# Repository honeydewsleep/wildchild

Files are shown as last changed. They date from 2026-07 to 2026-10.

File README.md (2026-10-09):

# Energy Ring Remix — WLED Notification Light

A fully parametric OpenSCAD rebuild of the
[ENERGY RING (ESP32 + WLED)](https://makerworld.com/en/models/2045449-energy-ring-esp32-wled)
desk lamp by DSL Design, with three revisions for use as a fleet of
email/notification lights:

1. **The base screws together** (coarse single-start thread, ~1.4 turns)
   — no more leaving the bottom on the desk. The single-start thread
   stops at a deterministic rotation, so the USB opening lands aligned
   with the ESP32's USB port every time.
2. **Battery base options**: 4×AA as a "cube" (two 2×AA boxes stacked),
   4×AA flat (four in a row), and an 8×AA double-layer for 12 V strips.
   Batteries load through a screwed door on the underside, so nothing
   unscrews (and no wires twist) for a battery change.
3. **Double-sided ring**: the LED strip mounts around the inside of the
   outer rim firing inward, and translucent diffusers on BOTH the front
   and back faces glow with the light color.

There are **two part series**:

- **Series M ("matched")** — `scad/matched/`, dimensioned from the
  original model's STLs. Same outside dimensions and look as the
  original (Ø96 skirt, tapered Ø95→86.6 shell, Ø180×40 ring, identical
  Ø27.8 stem + snap-diffuser interfaces), but the shell **threads onto
  the chassis** instead of resting on it. Cross-compatible: the new
  double-sided ring fits an original base, and the original ring fits
  the new threaded base. **Print this series to extend your fleet.**
- **Series A ("generic")** — a self-consistent standalone design
  (Ø150 two-half ring in a slotted Ø92 base) built before the original
  files were available. Kept as an alternative aesthetic.

## The original's problem, measured

Slicing the original STLs shows the base is a tapered shell that simply
*rests* on the chassis cup (Ø82.5 barrel in a Ø82.9 mouth, held by
gravity) — that's the part that stays behind on the desk. Series M
replaces that slip joint with the clocked thread.

## What to print — Series M (matched, recommended)

| Configuration | Parts |
|---|---|
| USB powered | `shell_threaded.stl` (or `shell.stl`), `chassis.stl`, `ring_double_sided.stl`, 2× `ring_ds_diffuser.stl` |
| 4×AA battery (cube boxes) | shell + `chassis_bat_cube.stl`, `battery_door_cube.stl`, + ring parts |
| 4×AA battery (flat holder) | shell + `chassis_bat_flat4.stl`, `battery_door_flat.stl`, + ring parts |
| 8×AA / 12 V | shell + `chassis_bat_flat8.stl`, `battery_door_flat.stl`, + ring parts |
| Thread calibration | `thread_test_collar.stl` + any chassis (same thread as Series A) |

**Three shell options** (the ring's stem is threaded in all cases,
crest at the original Ø27.8):

- `shell_free.stl` + `stem_locknut.stl` — **position-anywhere**: the
  stem drops through a free-spinning bore; aim the ring at any angle,
  then screw the knurled locknut onto the stem from inside the base
  (reach in through the open bottom before the chassis goes on) and
  tighten. The shell top gets clamped between the ring's shoulder and
  the nut. Slip the nut over the wire bundle before connecting the
  wires.
- `shell_threaded.stl` — the ring **screws into the base** (~3.5
  turns) and stops facing forward (single-start; trim with
  `ring_clock_adjust` if your printer shifts the stop a few degrees).
- `shell.stl` — plain crush-rib collar: any ring *push-fits*, including
  unmodified original rings. The threaded ring's crests still grip in
  it, so rings are interchangeable across all shells and original
  bases.

**Bottom-port options** (`shell_free_port_button.stl` — port window at
the original notch position + front dismiss-button hole):

- **Cable through the window**: pair with any standard chassis; the
  USB-C plug passes through the 13×10 window (17×14 funneled mouth)
  and plugs into the board inside.
- **Panel jack in the base** (`chassis_jack.stl`): a Ø9.7 hole in a
  recessed panel across the barrel passage takes a 9.1 mm USB-C chassis
  jack (nut from the open interior, pigtail to the board's 5V/GND).
  The clocked thread lands the shell's window framing the jack. The
  port face sits ~8 mm behind the shell surface, so the plug's
  overmold must be slimmer than ~13×10 mm for its first centimeter —
  typical cable ends fit, extra-chunky ones may not. Flash the board
  before assembly (or use WLED OTA); the board's own USB port isn't
  reachable through the wall in this build.

Ring: print `ring_double_sided.stl` in your body color (the rims are
opaque; white bounces the most light) and the two `ring_ds_diffuser.stl`
trays in translucent/natural. The trays snap in with double beads
exactly like the original diffuser, at any rotation — the stem bulb
is surface-mounted outside the rim wall (like the original), so the
light cavity is completely clear. Print one tray opaque for a
single-sided ring. The COB strip runs the full inside of the rim,
ending at the Ø20 wire hole.

## What to print — Series A (generic)

| Configuration | Parts |
|---|---|
| USB powered (aligned split notch) | `base.stl`, `bottom_plate.stl`, 2× `ring_half.stl`, 2× `ring_diffuser.stl` |
| USB powered (zero-alignment option) | `base_wallhole.stl`, `bottom_plate_plain.stl`, + ring parts |
| 4×AA battery (cube boxes) | `base.stl`, `battery_tub_4aa_cube.stl`, `battery_door_cube.stl`, + ring parts |
| 4×AA battery (flat holder) | `base.stl`, `battery_tub_4aa_flat.stl`, `battery_door_flat.stl`, + ring parts |
| 8×AA / 12 V | `base.stl`, `battery_tub_8aa_flat.stl`, `battery_door_flat.stl`, + ring parts |
| Thread calibration | `thread_test_collar.stl` (bottom 12 mm of the base only) |

Print the two `ring_half.stl` copies in your opaque color (white interior
diffuses best) and the two `ring_diffuser.stl` copies in translucent/natural
filament. For a **single-sided** ring, print one diffuser translucent and
one in opaque white — same parts.

All STLs are exported print-ready (no supports needed):

- `base*.stl` prints inverted (as exported) — threads and notch face up.
- Plates/tubs print desk-face down — threads face up.
- Ring halves print face down; diffusers and doors print flat.
- The battery tub ceiling bridges over the pocket (internal, cosmetic only).

**Suggested settings:** 0.2 mm layers, 3 walls, 15 % infill. PETG or PLA.

## How the USB alignment works (both series)

The thread is single-start, so the fully-tightened joint always stops at
the same rotation. In Series M the USB hole lives in the shell wall and
the ESP32's port lives in the chassis; the clocked thread stops the hole
right in front of the port (the barrel passage is 5 mm wider than the
hole for slack). In CAD the alignment is exact at seat; first-layer
squish on a real printer can rotate the seat point slightly, so:

1. Print `thread_test_collar.stl` (cheap, fast) and a chassis (or plate).
2. Screw together until snug. If the notch lands rotated, estimate the
   offset in degrees (±10° already works).
3. Set `plate_clock_adjust` in `scad/params.scad` to that offset (flip
   the sign if it gets worse), re-render, reprint the male part only.

The value is per printer+profile — calibrate once and every chassis,
plate and battery tub you print after that will clock correctly. In
Series A you can skip the game entirely with `base_wallhole.stl` +
`bottom_plate_plain.stl` (window fully in the wall, nothing to align).

Threads are 45° flanks, 5 mm pitch, 0.3 mm radial clearance
(`thr_clr`) — loosen to 0.4 if your printer runs tight.

## Electronics

- ESP32 DevKit (30-pin) snaps between the rails on the chassis floor
  (Series M) or plate/tub (Series A), USB end toward the notch angle.
  Feed the USB cable through the hole *before* plugging it in; leave a
  service loop.
- COB WS2812B strip (10 mm wide): Series M ring takes ~550 mm around
  the Ø176 inside of the outer rim (~180 LEDs at 332/m — set a WLED
  current limit, e.g. 1800 mA on a 2 A supply); Series A ring takes
  ~455 mm. Stick it centered, LEDs facing the ring center; start/end
  the strip at the wire hole at the bottom of the rim.
- Series M: wires run down the Ø20 stem bore into the base; Series A:
  through the tab channel and slot-floor hole. Either way leave ~15 cm
  of slack so the base can be unscrewed with everything connected.

### Battery wiring

| Pack | Chemistry | Connect |
|---|---|---|
| 4×AA | **NiMH (recommended)** — 4.8 V nominal | Pack + → strip 5 V and ESP32 5 V pin, pack − → GND |
| 4×AA | Alkaline — 6.0 V fresh | Add 1–2 series diodes (1N5817) to stay ≤5.3 V for the strip |
| 8×AA | 12 V pack | 12 V strip (WS2815 or 12 V COB) direct; buck converter (MP1584 etc.) → 5 V for the ESP32 |

Pack leads route up through the 8 mm hole in the tub top plate. A KCD1
rocker switch snaps into the cutout on the front wall of every tub
(disable with `switch_cutout = false`). Battery door takes two M3×8
self-tapping screws.

*About "the battery boxes from the fume extractor project":* I couldn't
find that project in the repos this session can see, so the pockets are
sized for the common 58×31.5×15.5 mm 2×AA boxes and 62×58×15.5 mm flat
4×AA holders, with wiggle room. If yours differ, edit `pocket_cube` /
`pocket_flat4` / `pocket_flat8` in `scad/params.scad` (L×W×H + a couple
mm) and re-render.

## Ring assembly — Series M (matched)

1. Stick the COB strip around the inside of the outer rim, centered;
   start/end at the wire hole at the stem angle, wires down the stem.
2. Snap a diffuser tray into each face (double snap beads, exactly like
   the original diffuser — firm push all around). The trays also
   rigidify the ring, so snap both in before handling roughly.
3. Mount per your shell: `shell_free` — drop the stem in, aim the
   ring, slip the locknut up the wires and tighten it from inside;
   `shell_threaded` — screw the stem in clockwise (viewed from above)
   until the shoulder seats facing forward; `shell` — push the stem in
   until the crush ribs seat. Wires continue into the chassis in all
   cases.

## Ring assembly — Series A (generic)

1. Drop a diffuser into each half's rebate (it's captive after joining).
2. Stick the COB strip around the inside of one half's outer rim,
   centered on the joint line; route the wires through the tab groove.
3. Join the halves: the two alignment pins on each half enter the
   sockets on the other (flip one half over — the tab stays at the
   bottom by design). A few dabs of CA or plastic glue on the rim.
4. Seat the tab in the base slot, wires through the slot-floor hole.

## Email notifications (the whole point!)

WLED lamps take simple HTTP commands on your LAN, so a small bridge
watches Gmail and flips presets:

- **`companion/gmail_wled_bridge.py`** — standalone bridge, stdlib
  Python, runs on any always-on machine (Pi, desktop). Polls Gmail
  over IMAP for unread mail from specific senders (or Gmail labels),
  switches all lamps to that rule's WLED preset, and returns them to
  idle once the mail is read. Setup instructions in the file header.
- **Home Assistant alternative**: the `imap` integration fires an
  event per incoming mail; an automation matching the sender calls
  the WLED integration (`light.turn_on` with a color, or select the
  preset entity). Same idea, no extra script, if you already run HA.

Either way, save your looks as WLED presets (1 = idle, 2 = red
breathe, ...) so you can restyle in the WLED app without touching the
bridge. With WLED Sync (one lamp sends, the rest receive) a single
command drives every lamp in the house.

## Rendering

```bash
./render.sh          # everything: STLs, fit checks, preview PNGs
./render.sh stl      # just the printable STLs
./render.sh check    # thread interference/engagement verification
```

Requires OpenSCAD (tested with 2021.01).

## Roadmap

- **Other shapes (heart, peace sign, …)** — planned next, as discussed.
  The double-sided construction (two flip-symmetric halves + captive
  diffusers + tab) is shape-agnostic; the circle modules in
  `scad/ring.scad` will be generalized to arbitrary outlines. Note the
  peace sign's interior bars will need a lighting decision (lit bars vs
  silhouette bars).
- Printed-contact AA holder (springs from salvaged holders) if the
  purchased-box pockets don't suit.

## Misc: capsule-filling funnel (`scad/misc/capsule_funnel.scad`)

Mini funnel for hand-filling size 00 capsules with a powder that
doesn't want to flow. Standalone file, unrelated to the lamp.

- `capsule_funnel_00.stl` — the spout is a thin **socket that slips
  over the capsule body** (Ø8.48 ID, 5 mm deep), so the hole is only
  limited by the capsule's own bore: **Ø7.64 mm** for a 00. A tube
  that inserts *into* the body (`spout="in"`) can't beat ~Ø6.5.
  Steep 68° cone, Ø30 mouth, 0.8 mm cone wall, 0.6 mm socket wall,
  34 mm tall. Prints mouth-down, no supports.
- `capsule_funnel_00_insert.stl` — spout goes **into** the body
  instead (4 mm, Ø7.49 OD at the shoulder tapering to Ø7.29 at the
  tip), so nothing can spill between funnel and capsule. The tube wall
  is a **single 0.45 mm extrusion line**; turn on thin-wall detection /
  Arachne in the slicer. Hole **Ø6.39 mm**. The cone shoulder rests on
  the capsule rim as a depth stop. Too loose/tight → `insert_clr`
  (0.15 test-printed too big to enter; single-line walls swell).
- `capsule_tamper_00.stl` — Ø5.9 rod with a disc handle to break
  bridges and pack the powder down. Fits through either funnel.
- `capsule_stand_00.stl` — 52×52×14.5 block: 8 wells for bodies
  (front two rows, 12 mm deep so 8 mm stands proud) and 8 shallower
  wells for the caps (back two rows). Every well has a 45° lead-in.
  `stand_cols` / `stand_rows` / `stand_cap_row` change the count.
- `3mf/capsule_filler_kit.3mf` — all four parts named and laid out on
  the plate, centred on (90, 90) so it fits any Bambu bed (A1 mini
  included). Open it in Bambu Studio and slice with your own presets.
  Rebuilt by `render.sh` via `scripts/make_3mf.py`.
- Other sizes: `-D 'capsule="000"'` / `"0"` / `"1"` (body OD table in
  the file). Loosen `socket_clr` if the socket is tight on your prints.

## Misc: Katie Bakes cookie cutter (`scad/misc/katiebakes_cutter.scad`)

Cutter + embosser in one part for the "Katie Bakes" script wordmark:
the blade follows the lettering outline (5 mm dough border), a 2.5 mm
plate spans the top, and the letters hang 2 mm below it so they press
into the dough as you cut. Tuned for 6 mm rolled dough → 1.5 mm imprint
(`dough_t`, `imprint`). Lettering 100 mm wide (strokes ≥ 1.2 mm after a
0.15 mm `bold` offset); the cutter is ≈ 123 × 45 × 9 mm.

- `katiebakes_cutter.stl` — print as exported (plate on the bed, blade
  and letters up), no supports; PLA/PETG, 0.4 nozzle, 2+ perimeters.
- `katiebakes_stamp.stl` — stamp-only version: the same lettering 2 mm
  proud of a 3 mm plate (cookie outline inset 1 mm) with an 80 mm bar
  handle, ≈ 110 × 32 × 25 mm. The plate is the depth stop, so it works on
  any dough thickness. Print as exported: letter faces on the bed, handle
  up, no supports; enable elephant-foot compensation (~0.2 mm).
- `scad/misc/katiebakes_logo.svg` — cream face layer of the logo,
  colour-masked from `katie-bakes.jpg` and traced with potrace. Swap in
  another SVG (black fill, letters only) to re-use the cutter for a
  different logo; `logo_w` sets the size.

## Misc: 3" round Katie Bakes set (`scad/misc/katiebakes_round.scad`)

Etsy-style cutter + stamp set for the two-line logo ("Katie" over
"Bakes", `katiebakes_logo2.svg`, enclosing circle Ø66). Separate cutting
rings so different heights can be printed for different cookies; the
stamp prints face up for crisp, tall lettering and takes a screw-in
handle. All parts print as exported, no supports.

- `katiebakes_round_stamp.stl` — Ø75.2 × 8.5 mm disc, lettering 3 mm
  proud, female thread (root r7.0, depth 1.2, pitch 3, 6.5 deep,
  clearance 0.30) opening in the base. Print face up; the thread cavity
  sits on the bed with 45° flanks, its ceiling is a short bridge. Ø75.2
  slides inside the cutter bore, so the ring doubles as a stamping guide.
- `katiebakes_round_knob.stl` — Ø36 mushroom knob, flat top on the bed,
  male thread up. `katiebakes_round_bar.stl` — 70 mm bar grip, same
  thread. Pick one (or both).
- `katiebakes_round_ring_9.stl`, `_13`, `_18` — Ø76.2 bore cutting rings,
  0.8 mm lip, 1.6 mm wall, 3 mm thumb flange with 45° underside; height
  9 / 13 / 18 mm for thin, standard and thick cookies. Print upright.
  Any other height: `-D ring_h=…`.
- `3mf/katiebakes_round_stamp_kit.3mf` — stamp + knob + bar on one plate
  (119 × 113 mm, fits any bed). `3mf/katiebakes_round_rings.3mf` — the
  three rings (179 × 179 mm; needs a 256 mm bed, else print the ring STLs
  singly).
- `./render.sh check` includes the thread clearance check (must be EMPTY).

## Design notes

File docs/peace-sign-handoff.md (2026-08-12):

# Handoff spec: peace-sign lamp (print-ready)

Turn the approved peace-sign mockup into print-ready parts. Read
`CLAUDE.md` first for build/verify workflow and the tolerances that must
be reused verbatim. This document contains every design decision already
made with the user — do not re-open them.

## What the user approved

`scad/matched/shapes_preview.scad`, `shape = "peace"`: the peace sign as
**one connected hollow glow region** — outer ring band plus the three
bars — rendered with `lamp_mock(solid = true)`. The user's explicit
revision: *"make the Peace sign interior also a hollow cavity with the
diffusers on both sides, so that I can also make that part light up"* —
i.e. the WHOLE sign glows, not just the ring; the bars are lit cavities,
not silhouettes.

Geometry of the approved outline (`peace2d()`):

- Outer circle Ø180 (matches the Series M ring), glow band `BAND = 22`
  (annulus Ø180 → Ø136).
- Bars 14 wide: one vertical full-diameter bar, two lower diagonals at
  ±45°, all clipped to the inner circle (+4 overlap so they fuse with
  the band).
- The three non-glowing window openings between the bars remain open
  (through-holes), each bounded by its own edge walls.
- Depth 40 front-to-back (same as `m_ring_t`).

## Construction — mirror `scad/matched/ring_ds.scad`

Build `scad/matched/peace_ds.scad` using the double-sided ring as the
template. Same construction language throughout:

- 2 mm walls (`m_rim_wall`) around the outline AND around each of the
  three window openings, full 40 mm depth. The bars' walls tie the
  structure together, so no spokes are needed.
- **Stem + bulb: reuse the ring's implementation.** The outline's lowest
  point is the Ø180 circle bottom (y = −90), exactly like the ring, so
  the threaded stem (`stem_thr_*` params, Ø20 wire bore through to the
  cavity) and the surface-mounted bulb (hull of squashed sphere +
  shoulder disc, minus `cylinder(r = 90 − m_rim_wall + 0.05)`) transfer
  nearly verbatim. Keep `stem_only()`-style export for fit checks and
  keep `ring_clock_adjust` phase trim so the seated sign faces forward.
- LED strip: 10.5 mm channel space along the inside of the outer band
  wall (Ø176 inside ≈ 553 mm of COB strip), LEDs firing inward. Strip
  start/end at the wire hole above the stem. The cavity is connected, so
  light spills from the band into the bars — the bars will glow dimmer
  than the band (acceptable; note it in the README). Do not attempt to
  route strip along the bars.
- Diffusers on BOTH faces: full sign outline with the three windows cut
  out, `m_dif_face_t` = 1.0 face. Snap retention like the ring's trays —
  10 mm skirts with double beads (0.45 proud, positions
  `m_dif_bead_z`) — but the skirts follow **offsets of the outline
  polygon** (and of each window edge) instead of circles: skirt outer
  surface = cavity edge − `diffuser_clr` (0.30). The peace outline is
  mirror-symmetric about the vertical axis, so ONE diffuser STL fits
  both faces (flip it over) — export one `peace_ds_diffuser.stl`,
  print ×2.
- Sharp-corner caution: where bars meet the band, `offset(r = ...)`
  rounds inside corners; that is fine here (the mockup already uses
  round-friendly geometry). Avoid `offset(delta)` on this shape — it
  can self-intersect at the 45° junctions.

## Parameters

Add a small `/* peace sign */` block in `scad/params.scad` (Ø180 outline,
band 22, bar width 14, reuse `m_ring_t`, `m_rim_wall`, `m_dif_*`,
`diffuser_clr`, `stem_thr_*`). No new tolerance values — everything fit-
critical already exists and is print-validated.

## Deliverables

1. `scad/matched/peace_ds.scad` — `part = "peace_ds" | "diffuser_peace"`.
   Sign exports face-down flat (NOT inverted — rings/diffusers export
   flat, only shells/bases invert). Diffuser exports flat, beads up.
2. `stl/peace_sign.stl` + `stl/peace_ds_diffuser.stl`, binary
   (`python3 scripts/stl2bin.py`), 0 render warnings.
3. Add the two parts to `render.sh` (stl section).
4. Verification before pushing (see CLAUDE.md for technique):
   - mesh probe: stem present at bottom, Ø20 bore open (ray-cast down
     the stem axis), three window through-holes open, faces at z = 0/40;
   - stem thread engagement vs the shell collar replica (pattern:
     `s_clearance` / `s_engagement` modes in `scad/fit_check.scad` —
     add `p_*` modes or reuse, clearance EMPTY, engagement NON-empty);
   - diffuser skirt vs cavity: clearance check with the 0.02 lift trick.
5. README: add the peace sign under a "Shape lamps" section (parts
   table row, assembly = same as ring, note the bars glow dimmer via
   spill light).
6. Commit (identity in CLAUDE.md), push, attach both STLs to the user
   with SendUserFile.

## Out of scope (do not build yet)

The heart (sharp inner V via mitered offset) and other shapes from
`shapes_preview.scad` — the user will ask separately. Do not modify
Series A, the shells, the chassis, or any validated tolerance.

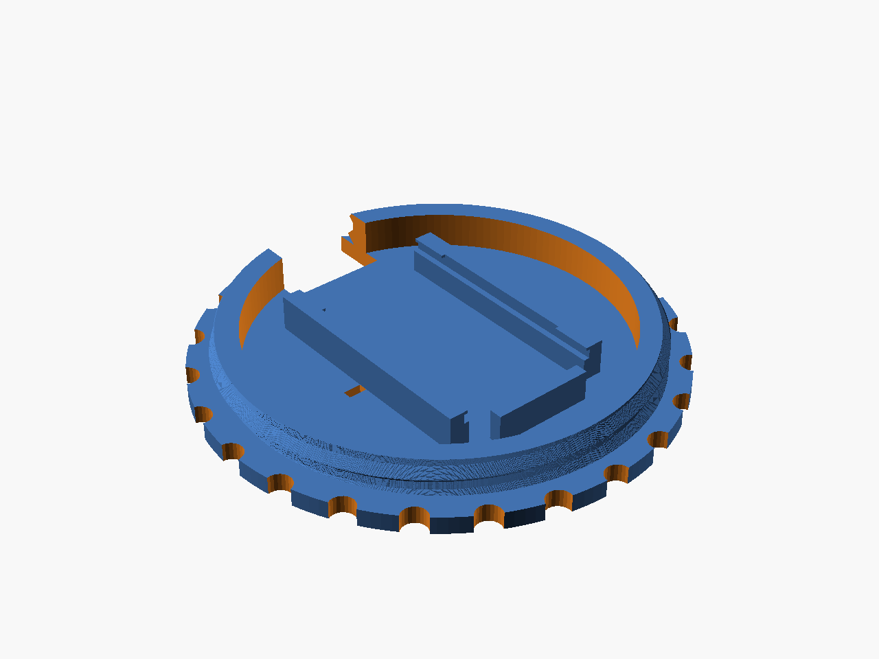
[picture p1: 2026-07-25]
preview/bottom_plate.png

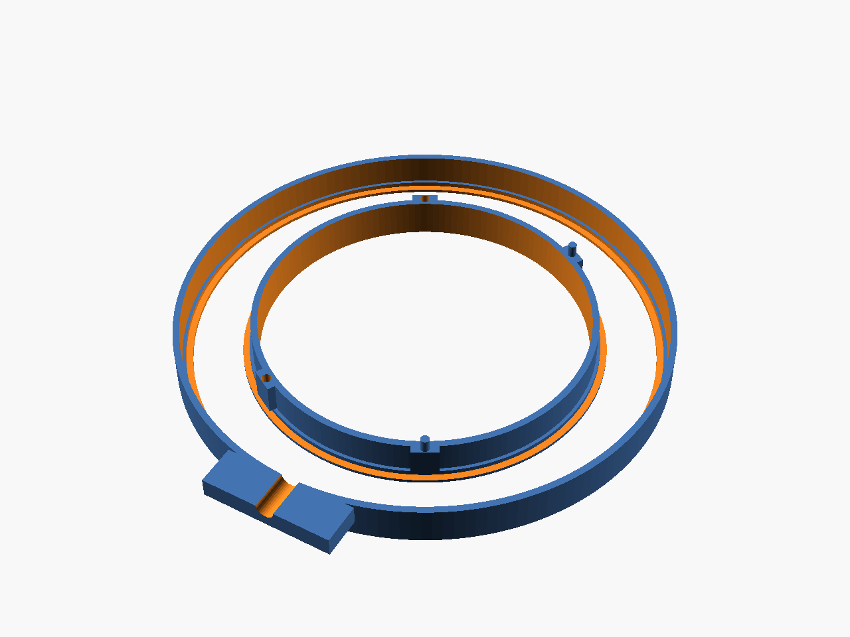
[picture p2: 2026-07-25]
preview/ring_half.png

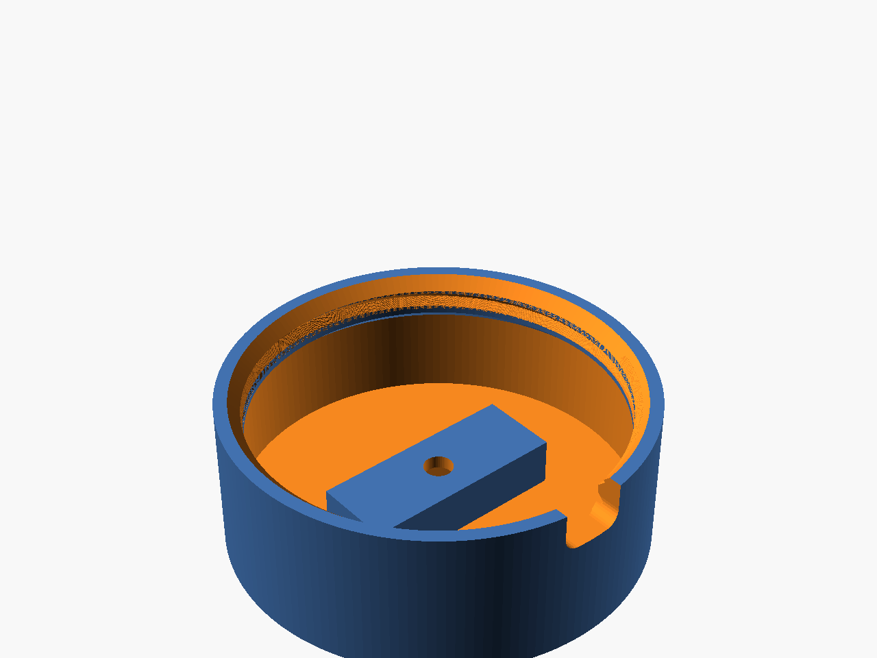
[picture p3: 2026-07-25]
preview/base.png

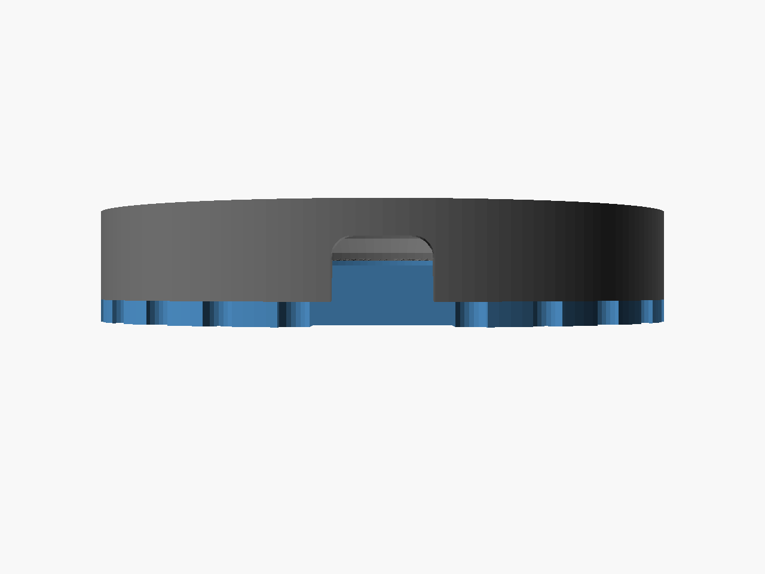
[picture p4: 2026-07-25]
preview/notch_alignment.png

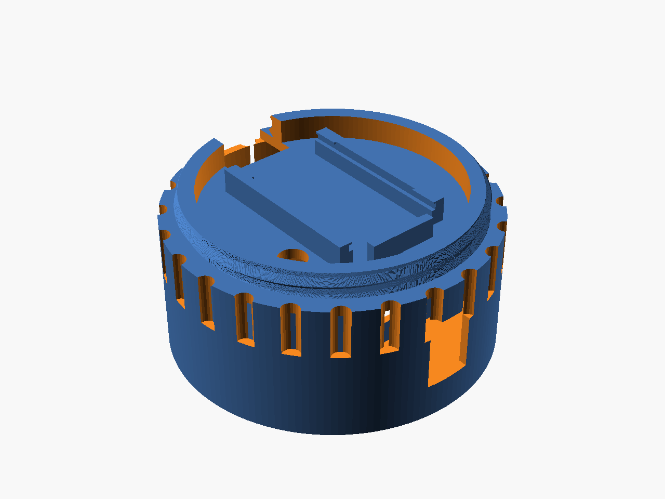
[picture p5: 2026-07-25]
preview/battery_tub_cube.png

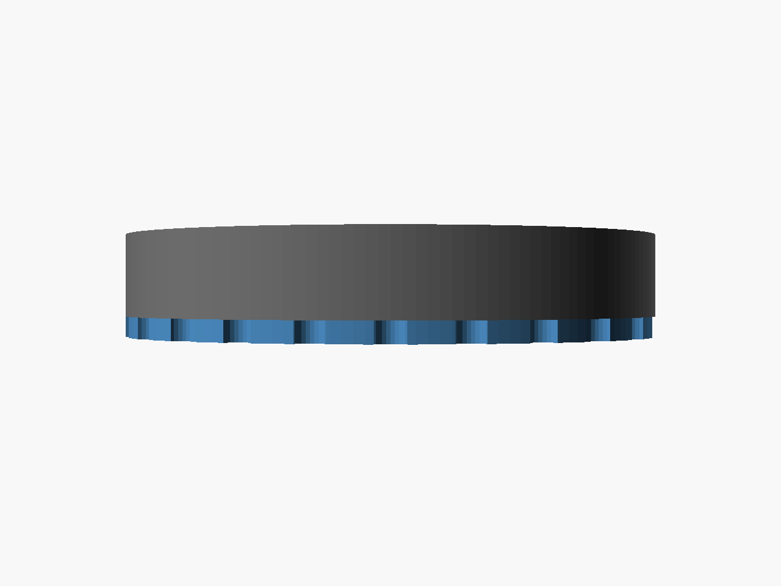
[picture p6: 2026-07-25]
preview/thread_section.png

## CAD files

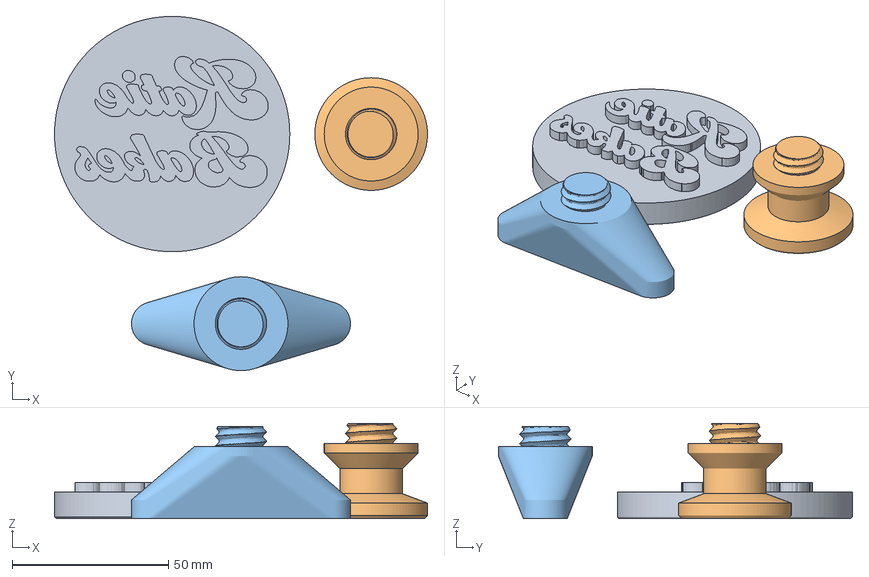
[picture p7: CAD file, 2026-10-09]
3mf/katiebakes_round_stamp_kit.3mf
119.2 x 113.2 x 30.5 mm
stamp
knob
bar

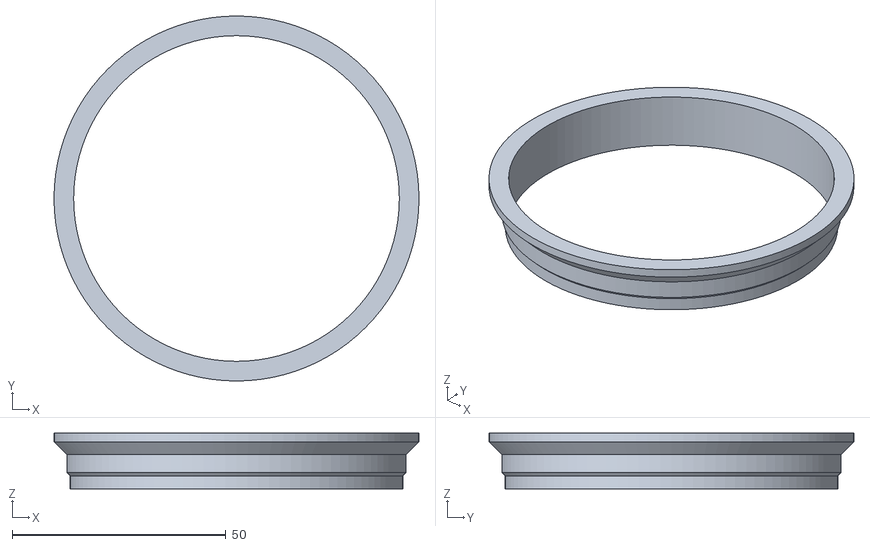
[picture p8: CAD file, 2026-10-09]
stl/katiebakes_round_ring_13.stl
85.4 x 85.4 x 13.0

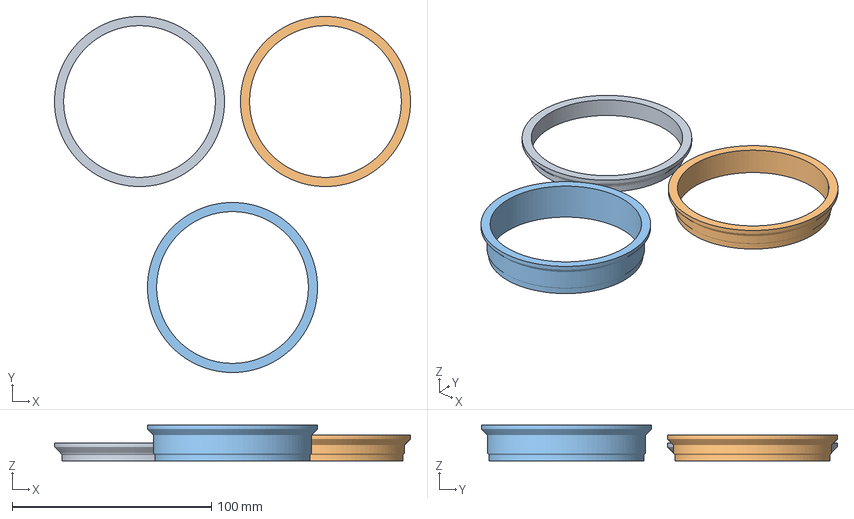
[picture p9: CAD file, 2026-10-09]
3mf/katiebakes_round_rings.3mf
178.8 x 178.8 x 18.0 mm
ring_9
ring_13
ring_18

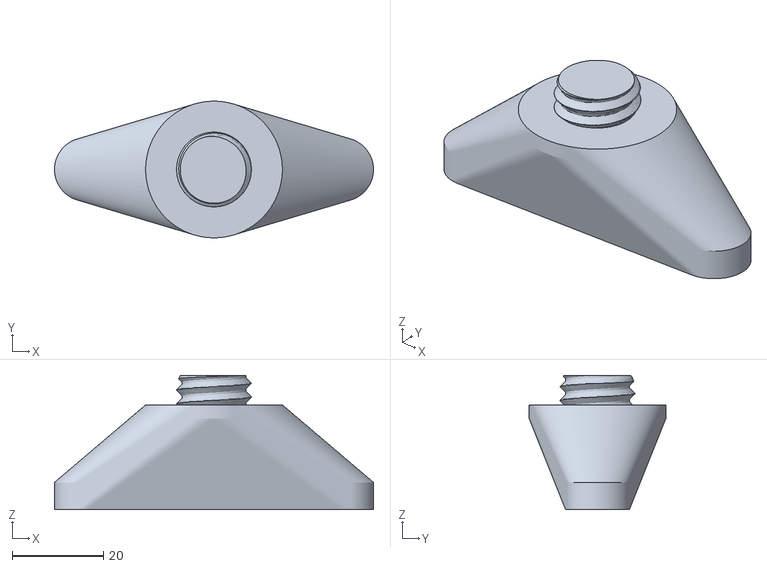
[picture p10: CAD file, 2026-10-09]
stl/katiebakes_round_bar.stl
70.0 x 30.0 x 29.5

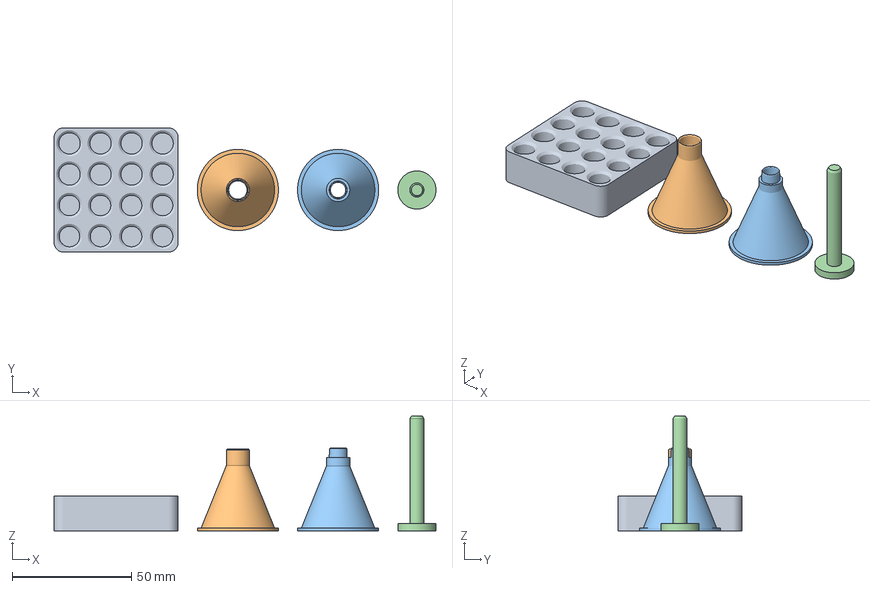
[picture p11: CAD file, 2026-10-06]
3mf/capsule_filler_kit.3mf
160.0 x 52.0 x 48.0 mm
stand
funnel_socket
funnel_insert
tamper

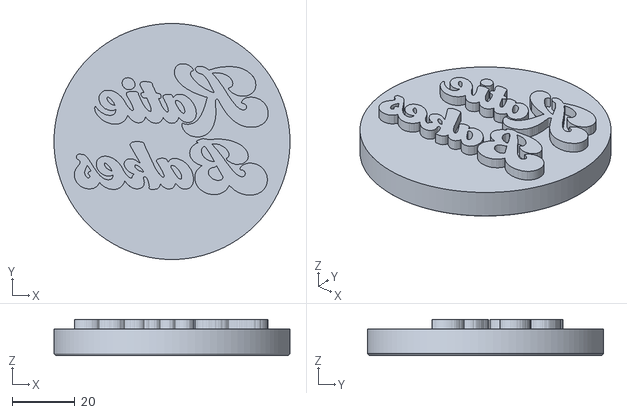
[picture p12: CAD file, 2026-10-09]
stl/katiebakes_round_stamp.stl
75.2 x 75.2 x 11.5

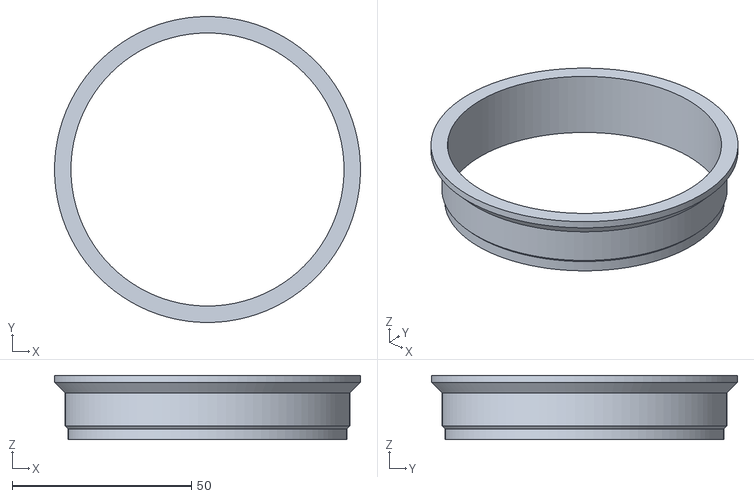
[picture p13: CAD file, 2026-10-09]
stl/katiebakes_round_ring_18.stl
85.4 x 85.4 x 18.0

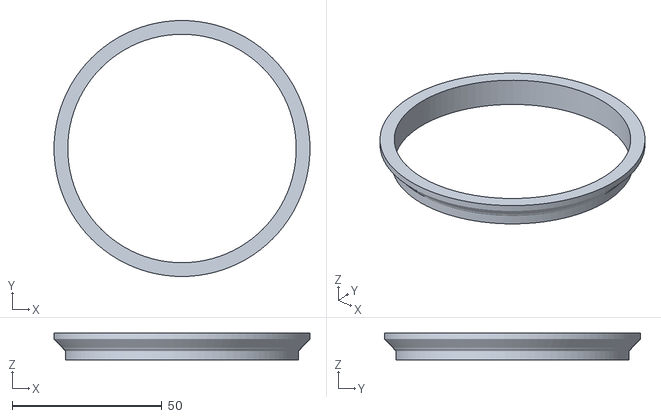
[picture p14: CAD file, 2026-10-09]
stl/katiebakes_round_ring_9.stl
85.4 x 85.4 x 9.00

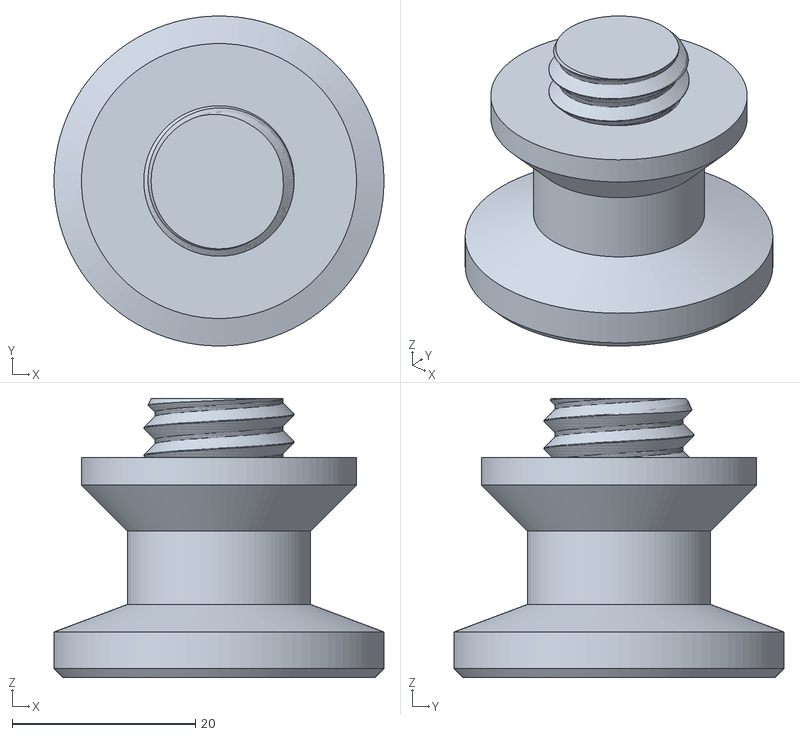
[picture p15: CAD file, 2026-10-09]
stl/katiebakes_round_knob.stl
36.0 x 36.0 x 30.5

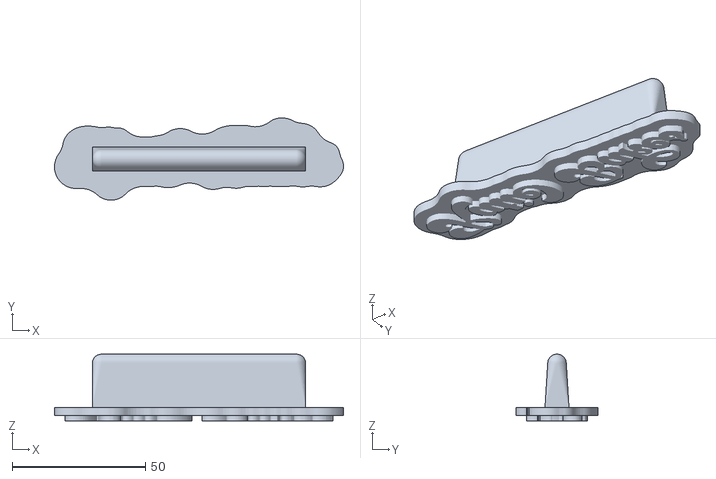
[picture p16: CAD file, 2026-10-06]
stl/katiebakes_stamp.stl
108.3 x 30.8 x 25.0

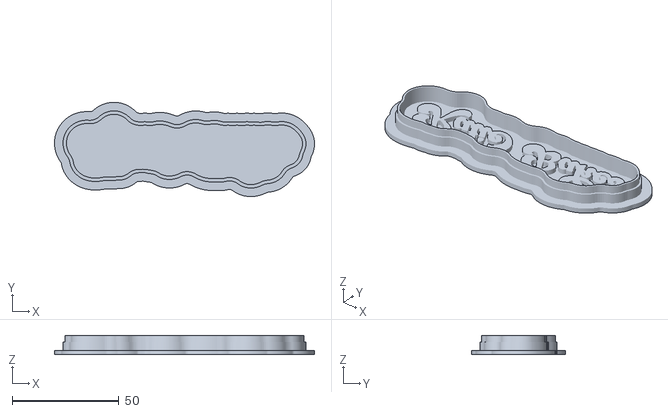
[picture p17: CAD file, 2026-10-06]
stl/katiebakes_cutter.stl
121.5 x 44.0 x 9.00

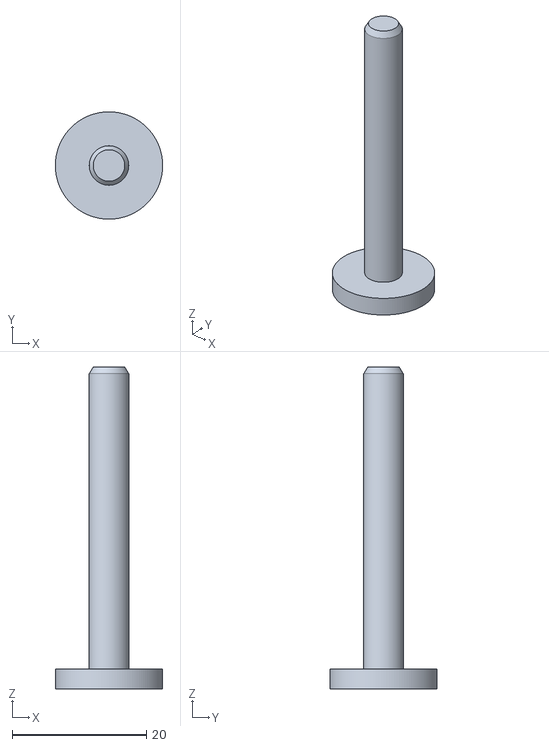
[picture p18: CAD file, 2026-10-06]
stl/capsule_tamper_00.stl
16.0 x 16.0 x 48.0

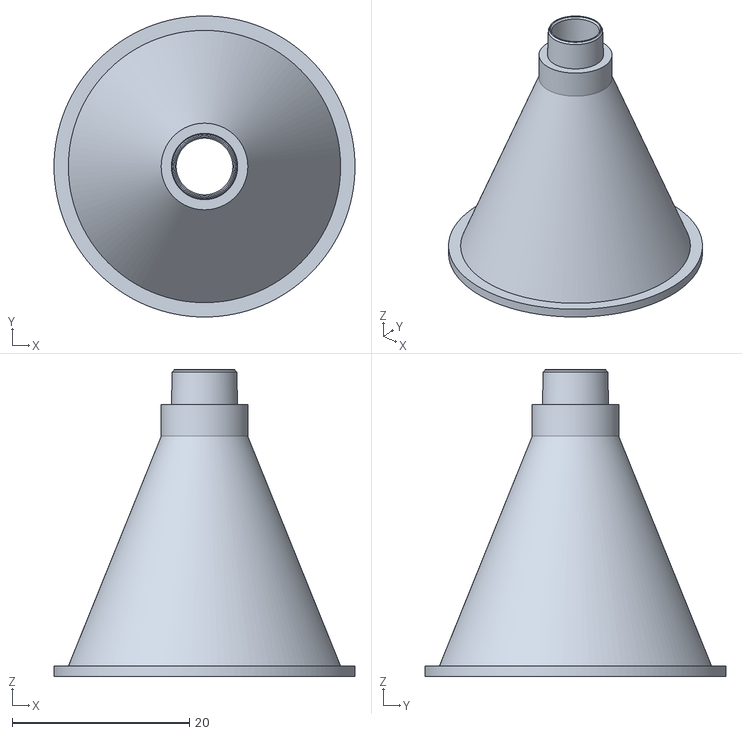
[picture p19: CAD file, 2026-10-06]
stl/capsule_funnel_00_insert.stl
34.0 x 34.0 x 34.7

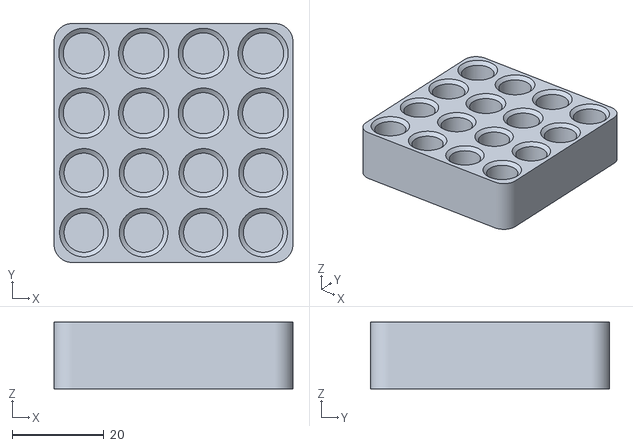
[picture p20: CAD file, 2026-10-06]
stl/capsule_stand_00.stl
52.0 x 52.0 x 14.5

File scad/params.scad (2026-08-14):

// =====================================================================
// Energy Ring Remix - shared parameters
// A parametric remix (ground-up rebuild) inspired by the "ENERGY RING
// (ESP32 + WLED)" lamp by DSL Design on MakerWorld (model 2045449).
// All dimensions in millimetres.
//
// Units: the lamp stands on the desk; base z=0 is the OPEN bottom rim
// of the base shell (where the screw-on plate seats), +z is up.
// The cable notch faces theta=270 degrees (-Y, "back" of the lamp).
// =====================================================================

/* ------------------------- global quality ------------------------- */
$fa = 2;
$fs = 0.5;
FN_ROUND   = 160;   // facets for large cylinders
EPS        = 0.01;

/* ---------------------------- the ring ---------------------------- */
ring_od          = 150;    // outer diameter of the ring
ring_rim_w       = 25;     // radial width of the rim (OD to hole)
ring_t           = 24;     // axial thickness (front face to back face)
ring_wall        = 2.0;    // outer / inner rim wall thickness
ring_face_t      = 2.4;    // front/back face flange thickness
win_r_in         = ring_od/2 - ring_rim_w + 5;   // glow window inner radius (55)
win_r_out        = ring_od/2 - 5;                // glow window outer radius (70)
rebate_depth     = 1.4;    // diffuser rebate depth into face flange
rebate_lap       = 2.0;    // how far the rebate ledge overlaps past the window
diffuser_t       = 1.2;    // diffuser plate thickness
diffuser_clr     = 0.30;   // radial clearance of diffuser skirts/rebate
                           // (0.15 test-printed a hair too tight)

led_strip_w      = 10.5;   // channel width for COB WS2812B strip (10 mm typ.)
led_strip_t      = 2.6;    // radial depth allowance for strip + adhesive

// ring-to-base tab
tab_w            = 40.6;   // tab width (chord, along X)
tab_len          = 10.0;   // how far the tab extends below the ring OD
tab_t            = 12.2;   // tab thickness (along ring axis)
wire_d           = 5.6;    // wire channel diameter through tab / walls

// half-joint alignment pins (angles are flip-symmetric about the Y axis:
// theta -> 180-theta maps pins onto sockets, so one STL mates with itself)
pin_angles       = [60, 300];
socket_angles    = [120, 240];
pin_d            = 2.6;
pin_h            = 4.0;
pin_clr          = 0.25;   // radial clearance for sockets
pin_boss_w       = 8;      // local wall thickening around pins
boss_r_in        = 51.2;   // pin boss radial extent (kept slim so the
boss_r_out       = 54.2;   // diffuser can drop past via its scallops)
pin_r_pos        = 52.6;   // pin/socket centre radius

/* ---------------------------- the base ---------------------------- */
base_od          = 92;
base_wall        = 2.4;
base_h           = 34;     // rim (z=0) to top face
base_top_t       = 2.8;    // closed top thickness
slot_len         = tab_w + 0.6;
slot_w           = tab_t + 0.5;
slot_depth       = tab_len + 0.5;
slot_wire_d      = 6.5;    // hole from slot floor into the cavity

// cable notch (feeds a USB plug through, then plugs into the board)
notch_angle      = 270;    // -Y
notch_w          = 14;     // width in the base wall
notch_h          = 9;      // height of the wall part of the notch
plate_notch_w    = 20;     // wider notch in the plate flange (alignment slack)

/* --------------------------- the thread --------------------------- */
// Coarse single-start 45-degree-flank thread, generated by twist
// extrusion. Single start => the seated (fully tightened) orientation
// is unique, which is what lets us clock the cable notches together.
thr_root_r       = 40.0;   // male root radius (minor radius of the rod)
thr_depth        = 1.6;    // radial depth of the thread rib
thr_pitch        = 5.0;    // axial travel per turn (single start => lead)
thr_len          = 7.0;    // engaged thread length (~1.4 turns)
thr_clr          = 0.30;   // radial clearance female-over-male (print fit)
thr_crest_deg    = 12;     // angular width of the flat crest
thr_steps        = 240;    // polygon facets for the thread profile
thr_slices_per_turn = 120; // extrusion slices per full turn

// CLOCK CALIBRATION: if, on your printer, the fully-tightened plate
// notch lands rotated from the base notch, set this (in degrees) to
// compensate and reprint ONLY the plate. Positive values rotate the
// seated notch position counter-clockwise viewed from below the lamp.
plate_clock_adjust = 0;

/* -------------------------- bottom plate -------------------------- */
plate_t          = 3.5;    // flange thickness
plate_boss_wall  = 4.0;    // radial wall of the male thread ring
grip_n           = 24;     // grip scallops around the flange edge
grip_d           = 5;      // scallop cutter diameter
foot_d           = 10.4;   // recess for adhesive rubber feet
foot_depth       = 1.0;
foot_r_pos       = 34;     // radial position of feet recesses

/* ---------------------- ESP32 board mounting ---------------------- */
// Default: ESP32 DevKit (30-pin), board approx 52.5 x 28.5 mm.
esp_l            = 52.5;
esp_w            = 28.5;
esp_clr          = 0.7;    // side clearance in the rails
rail_h           = 7.0;    // total rail height
rail_ledge_z     = 4.5;    // board rests at this height (pin tails hang below)
rail_t           = 3.0;    // rail base thickness
rail_lip         = 1.4;    // lip that hooks over the board edge
zip_slot         = [3.6, 1.8];  // zip-tie slots flanking the rails

/* ----------------------- battery tub options ---------------------- */
// Envelope sizes for common purchased battery boxes, with wiggle room.
// "cube"  = two 2xAA boxes (~58 x 31.5 x 15.5 each) stacked, or one
//           4xAA 2x2 holder (~58 x 32 x 29).
// "flat"  = one 4xAA flat holder (~62 x 58 x 15.5), 4 cells in a row x2.
// "flat8" = two flat 4xAA holders stacked (8 cells -> 12 V pack).
pocket_cube      = [60, 34, 33];
pocket_flat4     = [64, 60, 17.5];
pocket_flat8     = [64, 60, 34];
tub_od_cube      = 92;     // matches the base
tub_od_flat      = 96;     // slightly wider pedestal for the flat packs
tub_top_t        = 3.0;    // tub top plate (this is the "bottom plate" of the base)
tub_wall         = 2.4;
tub_floor_t      = 2.6;
tub_wire_hole_d  = 8;      // centre-ish pass-through for pack leads
door_t           = 2.4;    // sliding battery door thickness
door_clr         = 0.3;
door_ledge       = 3.5;    // floor ledge around the door opening

// optional rocker switch cutout (KCD1-style snap-in: 13.5 x 19.5 mm)
switch_cutout    = true;
switch_w         = 13.5;
switch_h         = 19.5;

/* ------------- "matched" series: original-model dimensions -------- */
// Measured from the original Energy Ring STLs (uploads analyzed with
// cross-section slicing). The original base = tapered shell slipped
// over a chassis cup (gravity fit - the part that stays on the desk).
// The matched series keeps every outside dimension but threads the
// shell onto the chassis with the same clocked thread as series A.
m_shell_h        = 50;     // shell height (rim to top face)
m_shell_od_top   = 86.6;   // outer diameter at the closed top (in use)
m_shell_od_rim   = 95.0;   // outer diameter at the open rim (desk end)
m_shell_wall     = 3.0;
m_shell_top_t    = 3.0;
m_stem_hole_d    = 28.2;   // ring stem hole in the shell top
m_collar_d       = 37;     // reinforcing collar under the top face
m_collar_h       = 10;     // grip depth for the ring stem
m_crush_rib      = 0.35;   // crush ribs in the collar bore (stem grip)
m_usb_notch      = true;   // low cable notch; disable when a panel
                           // jack supplies power instead
m_usb_w          = 11;     // USB hole in the shell wall at notch_angle
m_usb_h          = 7.5;
m_usb_z          = 2.0;    // above the shell rim

// bottom port window ("OG notch" position, sized for a USB-C plug
// overmold): straight 13x10 tunnel with a funneled 17x14 mouth so the
// plug self-centres. Serves two builds: bare cable through to a
// free-floating board (standard chassis), or framing the recessed
// panel jack on chassis_jack. Centre height = jack axis on chassis_jack.
m_port_window    = false;
m_port_w         = 13;
m_port_h         = 10;
m_port_zc        = 6;      // centre above the rim; window spans z 1..11
m_port_flare     = 2;      // funnel border per side at the mouth

// optional dismiss-button hole in the shell wall (12mm panel-mount
// momentary button, wired to a free ESP32 GPIO + GND; WLED short
// press -> Idle preset). Sits above the USB hole at the back.
m_button_hole    = false;
m_button_d       = 11.8;   // user's 11.6mm button; 15.8 for their
                           // 15.6mm one, 7.3 for PBS-110 minis
m_button_z       = 24;     // above the shell rim
m_button_angle   = 270;    // 90 = front (nicer when a jack takes the back)
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

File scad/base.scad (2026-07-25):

// =====================================================================
// Energy Ring Remix - main base unit (houses the ESP32 on the plate)
//
// z=0 is the open bottom rim where the screw-on bottom plate seats.
// Internal (female) thread lives in a boss ring just inside the wall.
// The cable notch at theta=270 is the lower half of the cable opening;
// the plate's wider notch forms the other half once screwed home.
//
// part = "base"          split cable notch (pairs with notched plate)
// part = "base_wallhole" enclosed cable window fully in the wall,
//                        above the plate (pairs with the plain plate,
//                        no clocking needed at all)
// part = "test_collar"   bottom 12 mm of the base only - cheap print
//                        for thread fit + clock calibration
// =====================================================================
include <params.scad>
use <lib/threads.scad>

part = "base";  // overridden with -D on the command line

base_ir      = base_od/2 - base_wall;            // 43.6
boss_bore_r  = thr_root_r + thr_clr;             // 40.3
boss_top_z   = thr_len + 1.6;                    // 8.6

module base_shell() {
    difference() {
        cylinder(h = base_h, d = base_od, $fn = FN_ROUND);
        // hollow interior, leaves the closed top
        translate([0, 0, -EPS])
            cylinder(h = base_h - base_top_t + EPS, r = base_ir, $fn = FN_ROUND);
    }
}

// internal boss carrying the female thread, with 45-degree cone
// transition above it (base prints inverted, so the cone avoids an
// internal overhang ring)
module thread_boss() {
    rotate_extrude($fn = FN_ROUND)
        polygon([
            [boss_bore_r, 0],
            [base_ir + 0.5, 0],
            [base_ir + 0.5, boss_top_z + (base_ir - boss_bore_r)],
            [boss_bore_r, boss_top_z]
        ]);
}

// pocket + reinforcing block under the top face that grips the ring tab
module slot_block() {
    w = slot_len + 5;
    d = slot_w + 5;
    h = slot_depth + 3;
    translate([-w/2, -d/2, base_h - h])
        cube([w, d, h]);
}

module slot_pocket() {
    translate([-slot_len/2, -slot_w/2, base_h - slot_depth])
        cube([slot_len, slot_w, slot_depth + 1]);
    // wire passage from slot floor into the cavity
    translate([0, 0, base_h - slot_depth - 6])
        cylinder(h = 7, d = slot_wire_d, $fn = 48);
}

// radial cutter for the open-bottom cable notch (half the cable hole);
// extrudes toward -Y, then rotates into place around the base axis
module wall_notch_cut(width, height) {
    rotate([0, 0, notch_angle - 270])
        rotate([90, 0, 0])
            linear_extrude(height = base_od)
                rounded_slot_2d(width, height, 3);
}

// enclosed rounded-rect window fully in the wall, above the plate thread
module wall_window_cut() {
    zc = 16.5; wh = 9;
    rotate([0, 0, notch_angle - 270])
        rotate([90, 0, 0])
            linear_extrude(height = base_od)
                hull() {
                    for (dx = [-1, 1], dz = [-1, 1])
                        translate([dx*(notch_w/2 - 3), zc + dz*(wh/2 - 3)])
                            circle(3, $fn = 32);
                }
}

module female_thread_cut() {
    thread_female_cavity(thr_root_r, thr_depth, thr_pitch, thr_len + 0.4,
                         thr_clr, starts = 1, phase = 0,
                         steps = thr_steps, slices_per_turn = thr_slices_per_turn,
                         crest_deg = thr_crest_deg);
    thread_mouth_chamfer(thr_root_r, thr_depth, thr_clr);
}

module base_body(split_notch = true) {
    difference() {
        union() {
            base_shell();
            thread_boss();
            slot_block();
        }
        slot_pocket();
        female_thread_cut();
        if (split_notch)
            wall_notch_cut(notch_w, notch_h);
        else
            wall_window_cut();
    }
}

// bottom 12 mm only: thread + rim + notch, for calibration prints
module test_collar() {
    intersection() {
        base_body(true);
        cylinder(h = 12, d = base_od + 2, $fn = 64);
    }
}

/* ------------------------- part selection ------------------------- */
// Exported STLs are print-ready: the base prints inverted (top face
// on the bed) so the internal threads and cable notch need no support.
if (part == "base")
    rotate([180, 0, 0]) base_body(true);
else if (part == "base_wallhole")
    rotate([180, 0, 0]) base_body(false);
else if (part == "test_collar")
    rotate([180, 0, 0]) test_collar();

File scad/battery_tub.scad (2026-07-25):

// =====================================================================
// Energy Ring Remix - screw-on battery tub (replaces the flat plate)
//
// Same male thread and clocking as the bottom plate, but the plate
// extends downward into a battery compartment. Batteries load through
// a screw-fastened door on the underside (2x M3 self-tapping), so the
// tub itself never needs to come off for a battery change.
//
// Pocket sizes fit common purchased battery boxes:
//   tub_4aa_cube : two 2xAA boxes (~58x31.5x15.5) stacked, or one
//                  4xAA 2x2 "cube" holder (~58x32x29)
//   tub_4aa_flat : one flat 4xAA holder (~62x58x15.5), 4 cells in a row
//   tub_8aa_flat : two flat 4xAA holders stacked -> 8 cells, 12 V pack
//
// part = tub_4aa_cube | tub_4aa_flat | tub_8aa_flat | door_cube | door_flat
// =====================================================================
include <params.scad>
use <lib/threads.scad>
use <bottom_plate.scad>   // male_thread_ring(), esp_rails(), plate_notch geometry

part = "tub_4aa_cube";

/* ------------------------- derived helpers ------------------------ */
function tub_h(pocket)       = tub_floor_t + pocket[2] + tub_top_t;
function opening_sz(pocket)  = [pocket[0] - 2*door_ledge, pocket[1] - 2*door_ledge];
function pad_x(pocket)       = pocket[0]/2 + 4.5;

ear_w    = 14;    // door ear tab width (along X)
ear_d    = 12;    // door ear tab depth (along Y)
recess_t = 2.5;   // door recess depth in the floor
tub_floor_t_eff = 3.2;   // slightly thicker floor than params default

/* -------- door outline: main rect + screw ear tabs at +/-X --------- */
module door_outline_2d(pocket, grow = 0) {
    op = opening_sz(pocket);
    ox = pad_x(pocket);
    square([op[0] - 0.6 + 2*grow, op[1] - 0.6 + 2*grow], center = true);
    for (sx = [-1, 1]) scale([sx, 1])
        translate([0, -ear_d/2 - grow])
            square([ox + ear_w/2 + grow, ear_d + 2*grow]);
}

/* ------------------------------ tub -------------------------------- */
module battery_tub(pocket, od, use_switch = switch_cutout) {
    H   = tub_floor_t_eff + pocket[2] + tub_top_t;
    ir  = od/2 - tub_wall;
    op  = opening_sz(pocket);
    px  = pad_x(pocket);
    switch_vertical = pocket[2] >= switch_h + 5;

    difference() {
        union() {
            // shell: outer cylinder with floor and top plate
            difference() {
                cylinder(h = H, d = od, $fn = FN_ROUND);
                translate([0, 0, tub_floor_t_eff])
                    cylinder(h = H - tub_floor_t_eff - tub_top_t, r = ir, $fn = FN_ROUND);
            }
            // rectangular pocket walls inside the bore
            translate([-(pocket[0]/2 + 2), -(pocket[1]/2 + 2), tub_floor_t_eff - EPS])
                cube([pocket[0] + 4, pocket[1] + 4, pocket[2] + EPS]);
            // door screw pads + gussets to the wall
            for (sx = [-1, 1]) scale([sx, 1, 1]) {
                translate([px, 0, recess_t])
                    cylinder(h = 8, d = 9, $fn = 48);
                translate([px, -3, recess_t])
                    cube([ir - px + 0.5, 6, 7.5]);
            }
            // male thread ring on the datum (top) face
            translate([0, 0, H]) male_thread_ring();
            // ESP32 rails ride on the tub top
            translate([0, 0, H]) esp_rails();
        }

        // battery pocket
        translate([-pocket[0]/2, -pocket[1]/2, tub_floor_t_eff])
            cube([pocket[0], pocket[1], pocket[2] + EPS]);
        // door opening + recess in the floor
        translate([0, 0, -EPS]) {
            linear_extrude(height = tub_floor_t_eff + 2*EPS)
                square([op[0], op[1]], center = true);
            linear_extrude(height = recess_t + EPS)
                door_outline_2d(pocket, grow = 0.3);
        }
        // screw pilot holes
        for (sx = [-1, 1])
            translate([sx*px, 0, recess_t - EPS])
                cylinder(h = 8.2, d = 2.7, $fn = 24);
        // pack-lead pass-through in the top plate
        translate([23, 12, H - tub_top_t - EPS])
            cylinder(h = tub_top_t + 2*EPS, d = tub_wire_hole_d, $fn = 48);
        // cable notch through the top plate edge + thread ring,
        // matching the bottom plate's notch (same clocking)
        rotate([0, 0, notch_angle - 270])
            translate([-plate_notch_w/2, -od/2 - 4, H - tub_top_t - EPS])
                cube([plate_notch_w, (od/2 + 4) - 31, tub_top_t + thr_len + 2]);
        // grip scallop band near the top of the wall
        for (i = [0:grip_n - 1])
            rotate([0, 0, (i + 0.5)*360/grip_n])
                translate([od/2, 0, H - 14])
                    cylinder(h = 14 + thr_len, d = grip_d, $fn = 24);
        // optional rocker switch cutout, front wall (theta=90)
        if (use_switch) {
            sw = switch_vertical ? [switch_w, switch_h] : [switch_h, switch_w];
            rotate([0, 0, 90 - 270])
                rotate([90, 0, 0])
                    translate([0, tub_floor_t_eff + pocket[2]/2, 0])
                        linear_extrude(height = od)
                            square(sw, center = true);
        }
        // feet dimples (locate adhesive rubber feet), angled to stay
        // clear of the door recess and its ear tabs
        for (a = [30, 150, 210, 330])
            rotate([0, 0, a])
                translate([od/2 - 6.5, 0, -EPS])
                    cylinder(h = 0.6 + EPS, d = foot_d, $fn = 48);
    }
}

/* ------------------------------ door ------------------------------- */
module battery_door(pocket) {
    difference() {
        linear_extrude(height = door_t)
            door_outline_2d(pocket, grow = 0);
        for (sx = [-1, 1]) {
            translate([sx*pad_x(pocket), 0, -EPS])
                cylinder(h = door_t + 2*EPS, d = 3.4, $fn = 24);
            // countersink on the outside (desk) face
            translate([sx*pad_x(pocket), 0, -EPS])
                cylinder(h = 1.6, d1 = 6.4, d2 = 3.4, $fn = 24);
        }
    }
}

/* ------------------------- part selection -------------------------- */
if (part == "tub_4aa_cube")
    battery_tub(pocket_cube, tub_od_cube);
else if (part == "tub_4aa_flat")
    battery_tub(pocket_flat4, tub_od_flat);
else if (part == "tub_8aa_flat")
    battery_tub(pocket_flat8, tub_od_flat);
else if (part == "door_cube")
    battery_door(pocket_cube);
else if (part == "door_flat")
    battery_door(pocket_flat4);

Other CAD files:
stl/capsule_funnel_00.stl
stl/shell_free_port_button.stl
stl/chassis_jack.stl
stl/shell_free_jack_button.stl
scad/bottom_plate.scad
scad/fit_check.scad
scad/matched/chassis.scad
scad/matched/ring_ds.scad
scad/matched/shapes_preview.scad
scad/matched/shell.scad
scad/matched/stem_locknut.scad
scad/misc/capsule_funnel.scad
scad/misc/katiebakes_cutter.scad
scad/misc/katiebakes_round.scad
scad/preview_assembly.scad
scad/ring.scad
stl/base.stl
stl/base_wallhole.stl
stl/battery_door_cube.stl
stl/battery_door_flat.stl
stl/battery_tub_4aa_cube.stl
stl/battery_tub_4aa_flat.stl
stl/battery_tub_8aa_flat.stl
stl/bottom_plate.stl
stl/bottom_plate_plain.stl
stl/chassis.stl
stl/chassis_bat_cube.stl
stl/chassis_bat_flat4.stl
stl/chassis_bat_flat8.stl
stl/ring_diffuser.stl
stl/ring_double_sided.stl
stl/ring_ds_diffuser.stl
stl/ring_half.stl
stl/shell.stl
stl/shell_free.stl
stl/shell_free_button.stl
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

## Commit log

2026-07-25 Parametric Energy Ring remix: threaded plate, battery tubs, 2-sided ring
    Ground-up OpenSCAD rebuild of the MakerWorld Energy Ring (ESP32+WLED)
    with three revisions:
    - Bottom plate screws onto the base with a coarse single-start thread;
    cable notches clock into alignment at full seat (calibratable), and
    the ESP32 mounts on the plate for easy access
    - Screw-on battery tubs for purchased AA boxes: 4xAA cube (2x 2xAA
    stacked), 4xAA flat, and 8xAA double-layer for 12V strips, with
    underside battery door and rocker switch cutout
    - Double-sided ring built from two identical flip-symmetric halves,
    inward-facing COB strip, captive diffusers front and back
    Includes thread fit-check scad, te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
    [base.scad, battery_tub.scad, bottom_plate.scad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]
2026-07-25 Add rendered STLs (binary) and verification previews
    All parts render clean with no manifold warnings. Verified:
    - seated plate vs base intersection is empty (0.3mm thread clearance)
    - thread engagement volume 580mm3 across the full 7mm thread length
    - cable notches concentric at full seat
    - right-hand thread (righty-tighty from below)
    Also switch PNG export to xvfb-run for headless rendering.
    Claude-Session: https://claude.ai/code/session_01X2kVqbg16SWHignoymBfnc
    [base.stl, base_wallhole.stl, battery_door_cube.stl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]
2026-07-25 Add matched series: original-dimension shell, chassis, and 2-sided ring
    Reverse-engineered the uploaded original Energy Ring STLs by mesh
    cross-sectioning. The original base is a tapered shell that rests by
    gravity on a chassis cup (O82.5 barrel in an O82.9 mouth) - the joint
    that separates when the lamp is picked up. The ring's hollow O27.8
    stem slip-fits an O28.2 hole in the shell top; the ring is single
    sided with one snap-in O180 diffuser tray.
    New scad/matched/ series keeps every original outside dimension but:
    - shell threads onto the chassis (same clocked thread as series A,
    same test-collar calibration); USB hole stops aligned with the
    ESP32 port
    - shell grips the ring stem with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
    [chassis.scad, fit_check.scad, params.scad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]
2026-07-25 Add matched-series STLs (binary) and assembly previews
    All 7 parts render clean, no manifold warnings. Diffuser tray volume
    within 3% of the original diffuser body, confirming the snap
    interface match.
    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
    [chassis.stl, chassis_bat_cube.stl, chassis_bat_flat4.stl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]
2026-07-26 Add threaded ring stem + shell_threaded variant (ring screws into base)
    Per feedback after test-printing the base joint: the ring stem now
    carries a single-start thread (4mm pitch, ~3 turns) with the crest
    held at the original Ø27.8, so the threaded ring still push-fits the
    crush-rib shell and unmodified original bases. New shell_threaded
    part has the matching female collar thread, generated through the
    same transform chain as the assembled stem so the seated ring faces
    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
    [fit_check.scad, params.scad, ring_ds.scad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]
2026-07-26 Render threaded-stem ring and shell_threaded STLs (verified)
    Stem thread checks: seated stem vs threaded collar intersection is
    empty (0.3mm clearance); 292mm3 rib engagement over the 13mm thread.
    No manifold warnings.
    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
    [ring_double_sided.stl, shell_threaded.stl]
2026-07-26 Add stem locknut + shell_free: position-anywhere ring mounting
    The ring's threaded stem drops through shell_free's free-spinning bore
    (shallow 7mm collar), gets aimed at any angle, and is clamped from
    inside the base by a knurled locknut threading onto the stem. Stem
    thread lengthened to 14.5mm for more nut engagement (crest unchanged,
    existing prints remain compatible).
    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
    [params.scad, shell.scad, stem_locknut.scad]
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2026-07-26 Fix test-print feedback: diffuser fit, boss/rim blend, Ø20 wire passage
    - Diffuser skirts: clearance 0.15 -> 0.30 per side, snap-bead bite
    symmetric 0.15 on both skirts (printed a hair too tight)
    - Trim the stem boss flush with the ring's outer cylinder: its flat
    wide end no longer stands proud of the curved rim at the sides
    - Widen the cavity-to-stem wire passage from Ø10 to a constant Ø20,
    the maximum the stem thread root allows
    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
    [params.scad, ring_ds.scad]
2026-07-26 Render loosened diffusers (0.30 clearance, 0.15 symmetric bead bite)
    Ring render with the boss blend + Ø20 passage follows separately.
    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
    [ring_diffuser.stl, ring_ds_diffuser.stl]
2026-07-26 Inset boss trim 0.05 to avoid degenerate coincident-surface geometry
    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
    [ring_ds.scad]
2026-07-26 Replace boss with rim-wrapping bulb (hull of oblate spheroid + shoulder)
    A flat-based cone cannot meet the curved rim cleanly: it either
    leaves proud corners or pinches to a zero-width cusp at the rim
    tangent (the source of the non-manifold warnings and the visible
    junction gap on the test print). The bulb wraps the rim like the
    original model does. Diffuser trays gain an outer-skirt gap arc that
    clears the bulb - install with the gap at the stem.
    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
    [ring_ds.scad]
2026-07-26 Render fit-fix round: bulb-boss ring + gapped, loosened diffusers
    Both manifold-clean. Diffuser clearance 0.30/side with 0.15 bead
    bite; ring has the rim-wrapping bulb and Ø20 wire passage.
    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
    [ring_diffuser.stl, ring_double_sided.stl, ring_ds_diffuser.stl]
2026-07-26 Surface-mount the ring bulb like the original (cavity stays clear)
    Test-fit feedback: the cavity-intruding bulb blocked the diffuser
    tray. Slice the bulb at the rim inner face (+0.05) so it welds
    through the 2mm wall only, exactly like the original's boss; restore
    full-circle diffuser skirts (no gap, any rotation) and full-length
    strip run.
    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
    [ring_ds.scad]
2026-07-26 Render surface-mount ring + full-skirt diffuser (verified)
    Both manifold-clean; wire passage verified present in the mesh.
    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
    [ring_double_sided.stl, ring_ds_diffuser.stl]
2026-07-26 Add shape-option visual mockups (heart, peace, star, hex, moon, cloud)
    Concept previews only - picked shapes get engineered into full
    print-ready parts with strip channel, snap trays, and stem.
    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
    [shapes_preview.scad]
2026-07-26 Shape mockup revisions: sharp heart inner V, fully-lit peace sign
    Heart inner outline uses mitered offset so the bottom point mirrors
    the top notch; peace sign bars are hollow glow cavities joined to the
    ring band, diffusers spanning the whole sign.
    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
    [shapes_preview.scad]
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2026-08-11 Add dismiss button: HA config + optional 12mm button hole in shell
    Email automation now re-fires only on counter increase or all-read,
    so a button dismissal sticks until genuinely new mail arrives. Adds
    hardware-button notes (WLED short-press -> Idle preset, syncs to all
    lamps) and a smart-button automation skeleton.
    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
    [params.scad, shell.scad]
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2026-08-11 Add USB-C jack hole option + shell_free_jack_button.stl
    12.6mm hole at the back for Gebildet-style 2-wire chassis jacks
    (above the barrel, clear interior for body and nut), 7mm dismiss
    button moved to the front.
    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
    [params.scad, shell.scad, shell_free_jack_button.stl]
2026-08-12 Jack shell rev: drop USB notch, lower jack hole to z=17
    Jack hole now sits just above the female thread; lowest position
    where the jack body still clears the chassis barrel while the shell
    is screwed on. USB notch removable via m_usb_notch param.
    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
    [params.scad, shell.scad, shell_free_jack_button.stl]
2026-08-12 Add agent handoff docs + stl2bin script
    CLAUDE.md captures the build/verify workflow, mesh conventions and
    print-validated tolerances; docs/peace-sign-handoff.md is the full
    engineering spec for the peace-sign lamp so a fresh session can build
    it without re-deriving anything. scripts/stl2bin.py moves the ASCII->
    binary STL converter into the repo.
    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
2026-08-13 Update shell hole params for actual hardware
    Button hole 11.8 (11.6mm button), jack hole 9.7 (9.1mm USB-C barrel)
    raised to z=22 so the mounting nut spins clear of the thread-boss ledge.
    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
    [params.scad]
2026-08-13 Resize shell holes for actual hardware; lift jack hole clear of nut
    Button hole 7.3 -> 11.8 (user's 11.6mm momentary button). Jack hole
    12.6 -> 9.7 (their USB-C barrel measures 9.1) and raised z17 -> z22 so
    the mounting nut spins clear of the internal thread-boss ledge, which
    was blocking it at the old height.
    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
    [shell_free_jack_button.stl]
2026-08-14 Bottom-port options: OG-position window shell + jack-panel chassis
    shell_free_port_button: 13x10 port window with funneled 17x14 mouth at
    the original notch position, plus the front 11.8 button hole. Works as
    a plain cable pass-through on any chassis, or over chassis_jack.
    chassis_jack: flat panel filling the barrel USB passage, face recessed
    just inside the thread sweep, with a 9.7 hole for the 9.1mm USB-C
    chassis jack. The clocked thread lands the shell window framing it.
    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
    [chassis.scad, chassis_jack.stl, params.scad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]
2026-10-06 Add size-00 capsule-filling funnel + tamper (scad/misc)
    Socket-over-body spout: the thin 0.6 mm socket sleeves the capsule
    body instead of inserting into it, so the hole is only limited by the
    capsule's own bore (Ø7.64 for a 00 vs ~Ø6.5 for an insert tube).
    Steep 68° cone, Ø30 mouth, flat grip rim, prints mouth-down. Capsule
    size table (000/00/0/1) and an "in" spout mode for comparison.
    Matching Ø7.1 tamper rod. Wired into render.sh; binary STLs committed.
    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
    [capsule_funnel.scad, capsule_funnel_00.stl, capsule_tamper_00.stl]
2026-10-06 Capsule funnel: thin insert-spout variant (0.45 mm single-line wall)
    Spout goes into the capsule body so nothing can spill between funnel
    and capsule. Tube wall is one extrusion line (insert_wall 0.45),
    insert_clr tightened to 0.15: hole Ø6.89 on a 00. Cone shoulder acts
    as the depth stop. Tamper resized to the smaller bore so one rod fits
    both funnels.
    Claude-Session: https://claude.ai/code/session_015xQMBnvCCXVDmheQWUojsk
    [capsule_funnel.scad, capsule_funnel_00_insert.stl, capsule_tamper_00.stl]
2026-10-06 Capsule kit: 8-capsule stand + plate-ready 3MF for Bambu Studio
    Stand: 4x2 body wells (12 mm deep, 0.4 clr) plus 4x2 shallower cap
    wells, 45° lead-ins, rounded block. New scripts/make_3mf.py packs
    binary STLs into a core-spec 3MF with named objects arranged on the
    plate; 3mf/capsule_filler_kit.3mf holds stand, both funnels and the
    tamper centred on (90,90) so it fits every Bambu bed. Wired into
    render.sh.
    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
    [capsule_filler_kit.3mf, capsule_funnel.scad, capsule_stand_00.stl]
2026-10-06 Insert funnel: slimmer, tapered neck (test print was a bit too big)
    insert_clr 0.15 -> 0.45 (single-line walls swell ~0.1-0.2 on dia) and
    a 0.10/side taper shoulder -> tip: OD 7.49 at the shoulder, 7.29 at
    the tip, hole Ø6.39. Tamper follows the bore (Ø5.9). 3MF rebuilt.
    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
    [capsule_filler_kit.3mf, capsule_funnel.scad, capsule_funnel_00_insert.stl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]
2026-10-06 Katie Bakes cookie cutter with built-in logo embosser
    New self-contained part in scad/misc/: a cutter whose blade follows the
    outline of the "Katie Bakes" script wordmark, with a top plate and the
    lettering hanging 2 mm below it so it imprints 1.5 mm into 6 mm rolled
    dough as you cut. Lettering is the cream face layer of the logo
    (katie-bakes.jpg), colour-masked and traced to SVG with potrace; strokes
    are thickened 0.15 mm/side so the thinnest are ~1.2 mm at 100 mm wide.
    Exported inverted (plate on the bed), 0 render warnings, mesh-probed.
    Claude-Session: https://claude.ai/code/session_01XZcLjayF5JgjeEkDXsxdfb
    [katiebakes_cutter.scad, katiebakes_cutter.stl]
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2026-10-09 Round set v2: face-up stamp, screw-in handles, cutter rings in 3 heights
    Replaces the snap-in insert with an Etsy-style set. The stamp is a
    Ø75.2 × 8.5 disc printed face up (3 mm lettering, crisp) with a female
    thread in its base; a mushroom knob and a bar grip carry the matching
    male thread (root r7, depth 1.2, pitch 3, 6.5 long, clr 0.30, 45° flanks
    from lib/threads.scad; clearance fit-check renders empty). Cutting rings
    are separate, Ø76.2 bore with a thumb flange, exported at 9/13/18 mm.
    make_3mf.py gains --cols/--title; two plate kits (stamp+handles, rings).
    0 render warnings; all meshes probed (lettering mirrored on the face).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
    [katiebakes_round.scad, katiebakes_round_bar.stl, katiebakes_round_insert.stl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]
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2026-11-01 iPad 12.9 mount: size the charger pocket from the listing photos
    The LULULOOK pill the original mount uses measures 67 x 31 x 5 mm, with
    the contact row 9.9 mm from its outer long edge and centred lengthwise
    (homography on the plate's VESA 100 screws in the mounted photo, pin pitch
    maps to 5.01 vs Apple's 4.97; the empty-plate photo's recess agrees). The
    first cut was a 62 x 32 eyeball estimate, which would not have taken the
    charger. Pocket now 67.8 x 31.8 (0.4 clearance), centre 5.7 inboard of
    the pins; cable exit and groove follow. Mount STLs and the two mount 3MF
    plates re-rendered (0 warnings, checks empty, probes pass); template and
    plugs unchanged.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
2026-11-10 iPad 12.9 mount: cut the pocket for the KOOVIVA 12.9/13" charger, add fit coupon
    The user's charger is the KOOVIVA 27W Smart Connector pill sold for the
    12.9" Pro / Air 13" (B0H2SRH64Z): 68 x 32 x 6 mm per its listing drawing,
    contacts centred lengthwise and ~8.6 mm from the outer long edge. Pocket
    is now 68.8 x 32.8, 5.6 deep (pill 0.4 proud so its pogo pins preload,
    1.4 mm floor with the cable exit and glue window), centre 7.4 inboard of
    the contact row. New part="chg_test": a 90 x 46 chunk of the real plate
    around the recess with one magnet pocket, to check charger and magnet fit
    in a short print before the full plate. Mount STLs, coupon and the two
    mount 3MF plates re-rendered: 0 warning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
2026-11-10 iPad 12.9 mount: charger pocket from caliper measurements (72 x 33 x 4.6)
    The KOOVIVA pill measures 72 x 33 x 4.6 mm with calipers; its listing
    drawing (68 x 32 x 6) was wrong. Pocket 72.8 x 33.8, 4.2 deep (pill 0.4
    proud, 2.8 floor), centre 7.6 inboard of the contact row (listing's
    8.6/32 edge distance scaled to the 33 width). Mount STLs, fit coupon and
    the two mount 3MF plates re-rendered: 0 warnings, checks empty, probes
    pass.
    Claude-Session: https://claude.ai/code/session_01Bwd9QhpeLLWPspRvoj7s2M
